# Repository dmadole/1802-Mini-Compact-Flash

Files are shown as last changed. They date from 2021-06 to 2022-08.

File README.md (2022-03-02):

# 1802-Mini-Compact-Flash
This is the compact flash card for the [1802/Mini](https://github.com/dmadole/1802-Mini) system. It supports the following features:

* Has on-board compact flash socket, no adapters are needed
* Software compatible with Mike Riley's IDE interface design
* Runs Elf/OS using standard Pico/Elf ROMs and software
* Jumper selectable for I/O ports 2 & 3, 4 & 5, or 6 & 7
* Jumper selectable interrupt flag or status signal to EF1-4
* I/O group selection in system equipped with expander card
* Supports DMA operation with 10x accelerated transfer rate
* Supports interrupt-driven operation for multi-tasking OS
* Compact flash completely buffer-isolated from expansion bus
* Activity indicator LED provided as driven by CF card
* Highly annotated silkscreen documents settings and pins
* Creates probably the fastest Elf/OS system in the world

Gerber files for the PCBs and PDF schematics can be found in [Releases](https://github.com/dmadole/1802-Mini-Compact-Flash/releases).

BOMS and any applicable errata or other notes can be found in [notes](https://github.com/dmadole/1802-Mini-Compact-Flash/tree/main/notes).

For availability of kits and bare PCBs please see http://madole.net/1802/mini/kits

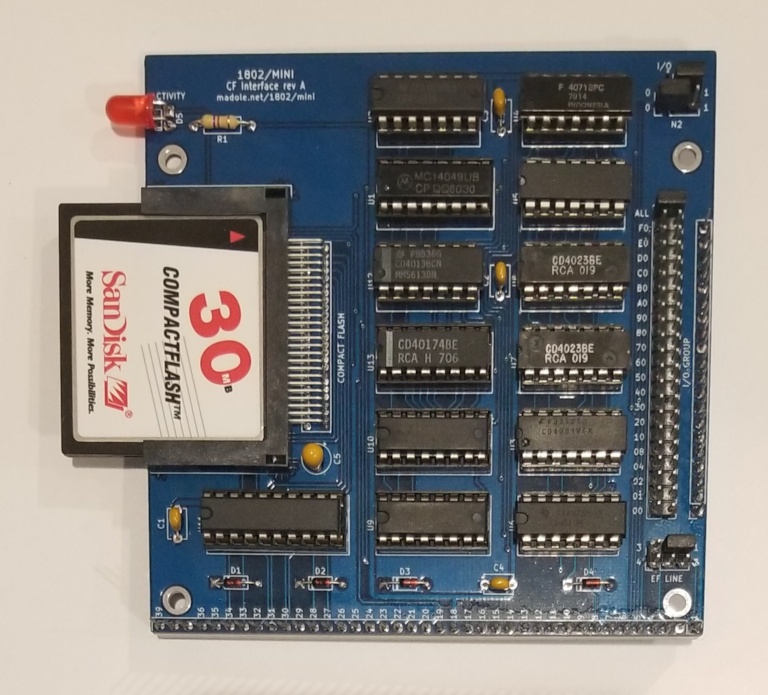
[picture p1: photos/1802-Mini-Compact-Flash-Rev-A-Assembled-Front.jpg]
1802/Mini Compact Flash Front

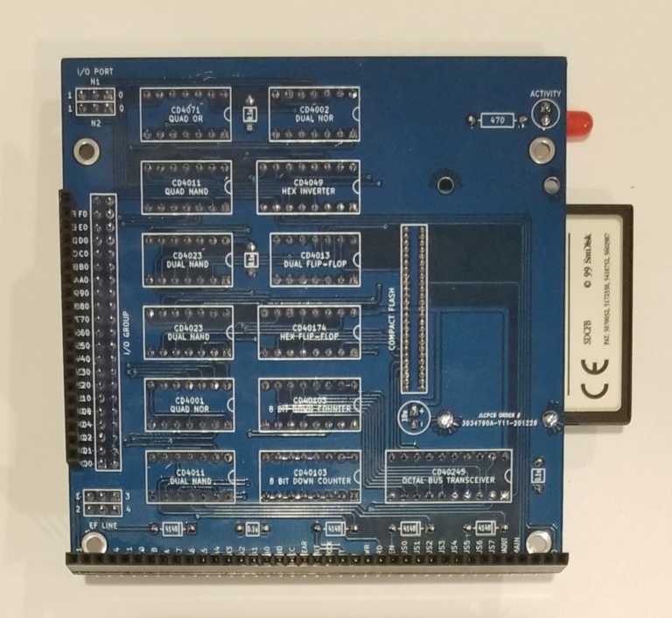
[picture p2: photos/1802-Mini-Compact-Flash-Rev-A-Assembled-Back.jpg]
1802/Mini Compact Flash Back


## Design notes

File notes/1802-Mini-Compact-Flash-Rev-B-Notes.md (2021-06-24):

# 1802/Mini Compact Flash Rev B Notes

The Rev B design in this folder is an interim release to corrects the compact flash socket footprint error in the Rev A board. It also incorporates a small improvement in the DMA latency by removing one gate delay, reducing latency by about 100ns. It is possible to field update the Rev A circuit to the Rev B circuit with two cut traces and two patch wires.

There is still an eventual plan for a Rev C design (referred to as "Rev B" in the Rev A notes) that will make some larger design changes but the timeline for that is unknown at this time since the Rev B works well enough and there are other priorities.

David Madole
May 30, 2021

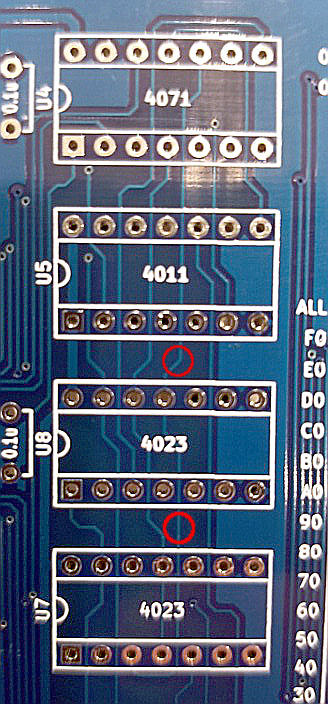
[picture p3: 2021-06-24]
patches/1802-Mini-Compact-Flash-Rev-A-to-Rev-B-Cut-Traces-Front.jpg

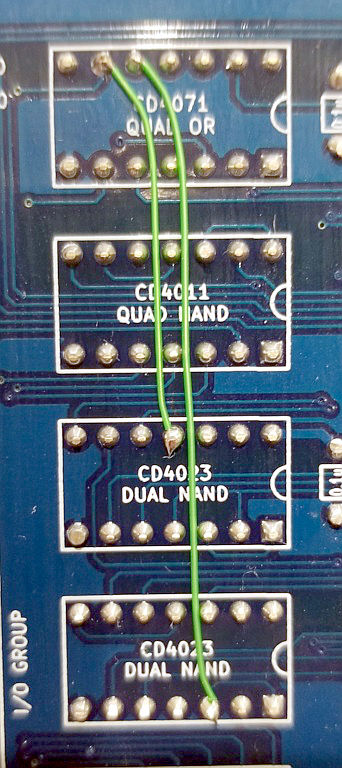
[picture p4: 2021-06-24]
patches/1802-Mini-Compact-Flash-Rev-A-to-Rev-B-Patch-Wires-Back.jpg

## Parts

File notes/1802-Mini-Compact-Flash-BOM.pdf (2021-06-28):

Please refer to these notes as applicable for the parts list below:

*A | The header pins for configuration jumpers are cut down from longer strips.
*B | The Samtec 39 pin connector, when ordering from Digikey, will always show zero stock because they are made-to-order. They will ship same or next day though.
*C | These parts may be omitted if group port selection will not be used. See assembly notes.

### COMPACT FLASH INTERFACE

Qty | Description | Manufacturer Manufacturer # | Vendor | Vendor # | Price | Qty | Total

Integrated Circuits
1 | CD4001 | U3,5 | TI | CD4001BE | Digikey | 296-2028-ND | 0.66 | 1.00 | 0.66
1 | CD4002 | U2 | TI | CD4002BE | Digikey | 296-2029-5-ND | 0.58 | 1.00 | 0.58
2 | CD4011 | U5-6 | TI | CD4011BE | Digikey | 296-2031-ND | 0.66 | 2.00 | 1.32
1 | CD4013 | U12 | TI | CD4013BE | Digikey | 296-2033-5-ND | 0.66 | 1.00 | 0.66
2 | CD4023 | U7-8 | TI | CD4023BE | Digikey | 296-2041-ND | 0.66 | 2.00 | 1.32
1 | CD4049 | U12 | TI | CD4049UBE | Digikey | 296-2055-5-ND | 0.66 | 1.00 | 0.66
1 | CD4071 | U4 | TI | CD4071BE | Digikey | 296-2062-ND | 0.66 | 1.00 | 0.66
2 | CD40103 | U9-10 | TI | CD40103BE | Digikey | 296-14080-5-ND | 1.68 | 2.00 | 3.36
1 | CD40174 (or 74C174 or 74HC174) | U13 | TI | SN74HC174N | Digikey | 296-1579-5-ND | 0.56 | 1.00 | 0.56
1 | CD40245 (or 74C245 or 74HC245) | U11 | TI | SN74HC245N | Digikey | 296-1584-5-ND | 0.66 | 1.00 | 0.66

Discrete Components
1 | Resistor 1/4 watt 470 | R1 | Stackpole | CF14JT470R | Digikey | CF14JT470RCT-ND | 0.10 | 1.00 | 0.10
1 | LED T1-3/4 | D5 | Valuepro | UT1871-81-M1-R | Jameco | 333973 | 0.12 | 1.00 | 0.12
4 | Diode 1N4148 | D1-4 | ON Semi | 1N4148 | Digikey | 1N4148FS-ND | 0.10 | 4.00 | 0.40
4 | Ceramic capacitor 0.1uF radial 0.2" | C1-4 | Valuepro | SR215C104KAA | Jameco | 544921 | 0.19 | 4.00 | 0.76

Interconnects
1 | Compact Flash Socket | | Samtec | CFT-125-01-L-D-RA-01-SL | Digikey | SAM9213-ND | 8.56 | 1.00 | 8.56
4 | Straight header 3 pins 0.1" (*A) | | Sullins | PREC040SAAN-RC | Digikey | S1012EC-40-ND | 0.51 | 0.30 | 0.15
4 | Jumper shunts 0.1" | | Sullins | STC02SYAN | Digikey | S9000-ND | 0.10 | 4.00 | 0.40
1 | Socket 39 pin 0.1" long tail (*B) | | Samtec | SSQ-139-03-T-S | Digikey | SAM1206-39-ND | 4.52 | 1.00 | 4.52
1 | Straight dual row header 21 position (*C) | | Sullins | PREC025DAAN-RC | Digikey | S2012EC-25-ND | 0.86 | 0.84 | 0.72
1 | Socket 20 pin 0.1" long tail (*B) (*C) | | Samtec | SSQ-120-03-T-S | Digikey | SAM1206-20-ND | 2.50 | 1.00 | 2.50

Sockets
8 | DIP socket 14 pin 0.3" | | On Shore | ED14DT | Digikey | ED3045-5-ND | 0.19 | 8.00 | 1.52
4 | DIP socket 16 pin 0.3" | | On Shore | ED16DT | Digikey | ED3046-5-ND | 0.19 | 4.00 | 0.76
1 | DIP socket 20 pin 0.3" | | On Shore | ED20DT | Digikey | ED3054-5-ND | 0.26 | 1.00 | 0.26

Mechanical
4 | 0.5 inch standoff spacer | | RAF | 4505-440-AL-7 | Jameco | 393474 | 0.49 | 4.00 | 1.96
1 | Circuit Board | | Madole | | JLCPCB | | 1.95 | 1.00 | 1.95
| | | | | | | Total | | 35.13

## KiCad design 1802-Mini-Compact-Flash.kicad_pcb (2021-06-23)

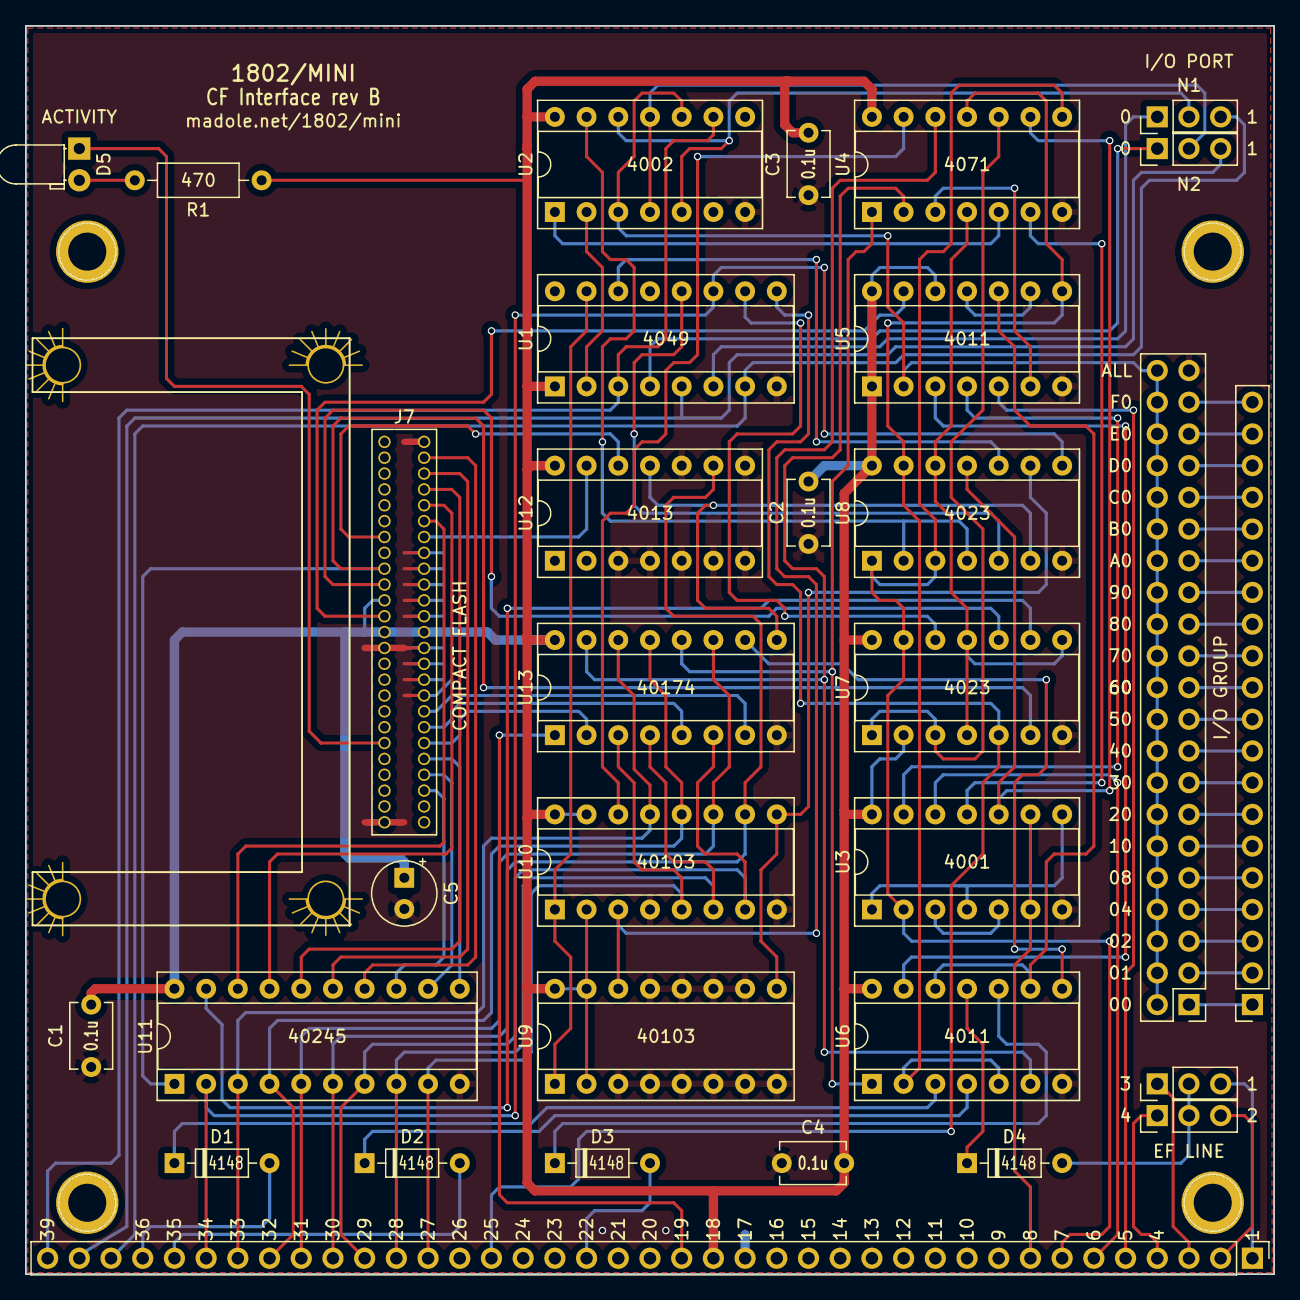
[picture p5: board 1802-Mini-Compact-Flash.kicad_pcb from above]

Board: 2 copper layers, 100.0 x 100.0 mm, 36 parts (0 on the bottom side), 101 nets.

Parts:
C1, C2, C3, C4: 0.1u; C_Disc_D5.1mm_W3.2mm_P5.00mm
C5: 10u; CP_Radial_Tantal_D5.0mm_P2.50mm
D1, D2, D3, D4: 4148; D_DO-35_SOD27_P7.62mm_Horizontal
D5: LED; LED_D3.0mm_Horizontal_O1.27mm_Z2.0mm
J1, J2, J3, J4: Mount; 1pin
J5: Expansion; Pin_Header_Straight_1x39_Pitch2.54mm
J6: Conn_01x20; PinSocket_1x20_P2.54mm_Vertical
J7: CF; samtec
J8: Conn_02x21_Odd_Even; PinHeader_2x21_P2.54mm_Vertical
JP1, JP2, JP3, JP4: Jumper_3_Bridged12; PinHeader_1x03_P2.54mm_Vertical
R1: 470; R_Axial_DIN0207_L6.3mm_D2.5mm_P10.16mm_Horizontal
U1: 4049; DIP-16_W7.62mm_Socket
U2: 4002; DIP-14_W7.62mm_Socket
U3: 4001; DIP-14_W7.62mm_Socket
U4: 4071; DIP-14_W7.62mm_Socket
U5, U6: 4011; DIP-14_W7.62mm_Socket
U7, U8: 4023; DIP-14_W7.62mm_Socket
U9, U10: 40103; DIP-16_W7.62mm_Socket
U11: 40245; DIP-20_W7.62mm_Socket
U12: 4013; DIP-14_W7.62mm_Socket
U13: 40174; DIP-16_W7.62mm_Socket

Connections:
/A0: J7.20, U13.2
/A1: J7.19, U13.5
/A2: J7.18, U13.7
/BUS0: J5.27, U10.5, U11.9, U13.3
/BUS1: J5.28, U10.6, U11.8, U13.4
/BUS2: J5.29, U10.7, U11.7, U13.6
/BUS3: J5.30, U10.10, U11.6, U12.9
/BUS4: J5.31, U10.11, U11.5, U13.11
/BUS5: J5.32, U10.12, U11.4, U13.13
/BUS6: J5.33, U10.13, U11.3, U13.14
/D00: J7.21, U11.11
/D01: J7.22, U11.12
/D02: J7.23, U11.13
/D03: J7.2, U11.14
/D04: J7.3, U11.15
/D05: J7.4, U11.16
/D06: J7.5, U11.17
/D07: J7.6, U11.18
/INTRQ: J7.37, U5.13
/~CS0: J7.7, U12.13
/~CS1: J7.32, U12.12
/~DASP: D5.1, J7.45
BUS7: J5.34, U1.11, U8.8, U11.2
CLK: U3.10, U4.9, U8.11
DMA: U3.11, U4.6
DMAIN_EN: U4.1, U6.1, U13.12
DMAOUT_EN: U4.2, U6.6, U13.15
GND: C1.2, C2.2, C3.2, C4.2, C5.2, J5.17, J7.1, J7.8, J7.9, J7.10, J7.11, J7.12, J7.14, J7.15, J7.16, J7.17, J7.39, J7.50, J8.41, U1.8, U2.7, U3.7, U4.7, U5.7, U6.7, U7.7, U8.7, U9.3, U9.4, U9.5, U9.6, U9.7, U9.8, U9.10, U9.11, U9.12, U9.13, U10.4, U10.8, U11.10, U12.3, U12.4, U12.5, U12.6, U12.7, U12.8, U12.10, U13.8
GROUP: U5.3, U6.13
INP: U4.10, U7.1, U7.3
INT_EN: U6.8, U13.10
IO: U4.4, U7.4, U7.8, U7.11, U8.12
N0: J5.39, U1.3, U2.9
N1: J5.38, JP1.3, U1.5
N2: J5.37, JP2.3, U1.7
unnamed: D1.1, U6.3
unnamed: D2.1, U6.4
unnamed: D3.1, U6.10
unnamed: D4.1, U6.11
unnamed: D4.2, JP3.2, JP4.2
unnamed: D5.2, R1.2
unnamed: J6.1, J8.1
unnamed: J6.2, J8.3
unnamed: J6.3, J8.5
unnamed: J6.4, J8.7
unnamed: J6.5, J8.9
unnamed: J6.6, J8.11
unnamed: J6.7, J8.13
unnamed: J6.8, J8.15
unnamed: J6.9, J8.17
unnamed: J6.10, J8.19
unnamed: J6.11, J8.21
unnamed: J6.12, J8.23
unnamed: J6.13, J8.25
unnamed: J6.14, J8.27
unnamed: J6.15, J8.29
unnamed: J6.16, J8.31
unnamed: J6.17, J8.33
unnamed: J6.18, J8.35
unnamed: J6.19, J8.37
unnamed: J6.20, J8.39
unnamed: JP1.1, U1.4
unnamed: JP1.2, U2.4, U2.11
unnamed: JP2.1, U1.6
unnamed: JP2.2, U2.5, U2.12
unnamed: U1.2, U2.2
unnamed: U1.10, U7.12
unnamed: U1.12, U8.5
unnamed: U1.14, U8.10
unnamed: U1.15, U9.1, U10.1
unnamed: U3.1, U3.4, U3.8
unnamed: U3.3, U3.5
unnamed: U3.13, U5.4
unnamed: U4.3, U5.6
unnamed: U5.10, U6.9, U6.12
unnamed: U4.12, U9.14, U10.3
unnamed: U4.13, U10.14
PORT2: U2.13, U8.2, U8.4
PORT3: U2.1, U4.5
SC0: J5.6, U3.12
SC1: J5.5, U5.5
TPA: J5.8, U3.6, U3.9
TPB: J5.7, U3.2, U4.8, U7.13, U8.1, U8.3
VCC: C1.1, C2.1, C3.1, C4.1, C5.1, J5.18, J7.13, J7.36, J7.38, R1.1, U1.1, U2.14, U3.14, U4.14, U5.1, U5.12, U5.14, U6.14, U7.2, U7.14, U8.14, U9.2, U9.15, U9.16, U10.2, U10.15, U10.16, U11.20, U12.14, U13.16
~CLEAR: J5.19, U13.1
~CTL_LE: U8.6, U12.11, U13.9
~CTR_LE: U8.9, U9.9, U10.9
~DATA: U7.9, U11.19
~DMAIN: D1.2, J5.36
~DMAOUT: D2.2, J5.35
~EF1: J5.1, JP3.3
~EF2: J5.2, JP4.3
~EF3: J5.3, JP3.1
~EF4: J5.4, JP4.1
~GROUP: J8.2, J8.4, J8.6, J8.8, J8.10, J8.12, J8.14, J8.16, J8.18, J8.20, J8.22, J8.24, J8.26, J8.28, J8.30, J8.32, J8.34, J8.36, J8.38, J8.40, J8.42, U2.3, U2.10, U5.2
~INTERRUPT: D3.2, J5.22
~INTRQ: U5.9, U5.11
~IORD: J7.34, U7.6, U11.1
~IOWR: J7.35, U7.10
~MRD: J5.25, U1.9, U7.5
~ZERO: U4.11, U5.8, U6.2, U6.5, U8.13

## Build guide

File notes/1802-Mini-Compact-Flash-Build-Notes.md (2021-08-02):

# 1802/Mini Compact Flash Assembly Notes

Follow usual assembly practices, which I will not document here. I recommend installing the lowest-height components first (resistors, diodes, right-angle connectors), then the next higher (sockets), and so on.

Please see any [applicable errata](https://github.com/dmadole/1802-Mini-Compact-Flash/tree/main/notes) before assembling.

## Compact Flash Connector

The board is designed for a through-hole compact flash connector to make assembly easier, but it is still 0.05-inch pitch on the leads, so soldering needs to be done carefully. I recommending soldering one pin at a time, under magnification, with just the minimum amount of solder to make a good connection, and keep your tip clean. This will help avoid bridges. Sometimes additional flux can help as well as it increases the surface tension of the solder.

The connector is physically retained to the board with four additional plastic posts. These are designed to have solder flowed into the holes which wick around them to secure the connector in place. I prefer to add enough extra solder to completely cover the plastic, but it's not important to securing them.

## Address and EF Line Selection

For compatibility with standard Pico/Elf and other software designed for a "Mike Riley" type IDE interface, use the jumpers to select ports 2-3 before installing. This is done by jumpering N1 to 1 and N2 to 0. The card is able to assert an EF line to signal when a transfer is complete; this is intended primarily for interrupt-driven software. For normal use, this can be disabled by leaving the EF LINE jumper off, or placing it on the center two pins.

## Port Group Selection

This card is able to be used in conjunction with another card with port group selection logic to allow bank-switching of the 1802 port address space to increase expandability. When not used with group selection, a jumper should be placed in the ALL position to permanently enable the card. If group selection is not going to be used, the I/O group jumper pins and stacking connector can be omitted, but the ALL position still needs to be selected, in this case, it can be done with a soldered wire.

## DMA Operation

This card is compatible with standard Pico/Elf or "Mike Riley" IDE interface software, but for faster performance, it also supports DMA-driven transfers. There are no additional hardware options needed to support DMA, just the appropriate software. See the "hydro" loadable module for Elf/OS for example.

## Lead Trimming

I like to cut all the pins on the back of the board, even the IC sockets, so they are tight with the solder. This can help with clearance on stacked boards, especially with a metal can oscillator. I then also sand over the surface lightly with an emery board to even them a little and remove sharp edges. Of course if you take this latter step, you will need to clean the board well after and be careful since the dust is conductive and probably contains lead, depending on your materials.

## Jumper Settings

The following settings are recommended for use with Elf/OS. These will set the I/O address to ports 2 and 3 anddiable the use of any EF line. The use of EF lines is intended for facilitating future interrupt-driven software, and this is not necessary for Elf/OS. These settings will give compatibility with the Pico/Elf which is the most common Elf/OS platform.

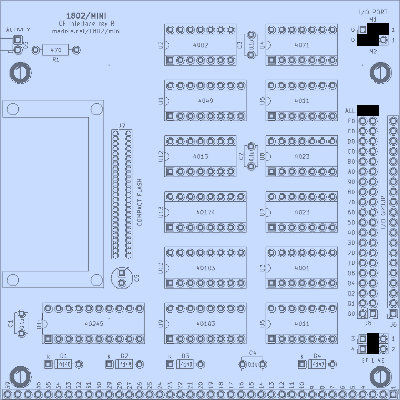
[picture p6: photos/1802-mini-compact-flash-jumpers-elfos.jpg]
1802/Mini Compact Flash Jumpers


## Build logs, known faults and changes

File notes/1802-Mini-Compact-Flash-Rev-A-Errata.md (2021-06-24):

# 1802/Mini Compact Flash Rev A Notes and Errata

The Rev A design in this folder has a board layout issue with the compact flash connector footprint. It is easily resolvable by cutting off one of the mechanical support pins from the socket that does not align with the PCB hole.

I have also made significant design changes to the design since then that are not yet documented. The primary reason for the changes is to increase timing margin for DMA operations to support high processor clock rates, with the intention of supporting reliably operation to 6 Mhz without having to have optimal parts. Secondary changes are a reorganization of gate usage to allow some chips to be omitted if DMA and interrupt operation is not needed, to reduce the parts count.

That said, the Rev A board does work with the layout caveat noted above, and if DMA operation is not desired or if care is taken on CPU clock speed and/or careful selection of parts is done to support higher clock speeds. At some point I will produce a Rev B that formalizes these changes.

David Madole
May 17, 2021

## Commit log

2021-06-23 Add BOM
    [1802-Mini-Compact-Flash-BOM.xlsx]
2021-06-27 Added notes and references to BOM
    [1802-Mini-Compact-Flash-BOM.xlsx]
2021-06-28 Correct mfr part no of single row header
    [1802-Mini-Compact-Flash-BOM.xlsx]
